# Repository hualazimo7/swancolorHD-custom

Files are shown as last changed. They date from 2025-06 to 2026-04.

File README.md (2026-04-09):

# swancolorHD
An open-source WonderSwan Color consolizer.

This project is in a somewhat usable stage right now.
Additionally, it needs the video core from sameer, to be [found here](https://github.com/hdl-util/hdmi).

## About
This project is an open-source consolizer for the WonderSwan Color handheld, based on a Tang Nano 9k FPGA board (which has a GW1NR-LV9QN88P FPGA on it).

Custom version [here](./PCB_CSUTOM/)  
Lite version [here](./Lite/)  

## PCB


### PCB BOM
| **Reference** | **Part** | **Link** |
---------|------|------|
|FPC1    | FFC connector with 24 pins, 0.5mm pitch, bottom contacts | [LCSC](https://lcsc.com/product-detail/FFC-FPC-Connectors_XUNPU-FPC-05F-24PH20_C2856805.html)|
|U1      | Arduino Nano | [AliExpress](https://aliexpress.com/item/1005002966043359.html)|
|U2      | Tang Nano 9k | [AliExpress](https://aliexpress.com/item/1005004275570427.html)|
|U3      | TPS62221DDCR | [LCSC](https://lcsc.com/product-detail/DC-DC-Converters_Texas-Instruments-TPS62221DDCR_C398348.html)|
|USB1    | Micro USB connector | [LCSC](https://lcsc.com/product-detail/USB-Connectors_XKB-Connectivity-U254-051T-4BH23-S2S_C482361.html)|
|JOY1    | SNES controller connector 90° | [AliExpress](https://aliexpress.com/item/32895254743.html)|
|C1      | 4.7 uF capacitor (1206) | [LCSC](https://lcsc.com/product-detail/Multilayer-Ceramic-Capacitors-MLCC-SMD-SMT_FH-Guangdong-Fenghua-Advanced-Tech-1206B475K500NT_C29823.html)|
|C2 | 10 uF capacitor (1206) | [LCSC](https://lcsc.com/product-detail/Multilayer-Ceramic-Capacitors-MLCC-SMD-SMT_Samsung-Electro-Mechanics-CL31A106KBHNNNE_C13585.html)|
|L2 | 10 uH inductivity (1206) | [LCSC](https://lcsc.com/product-detail/Inductors-SMD_FH-Guangdong-Fenghua-Advanced-Tech-CMI321609X100KT_C1051.html)|
|Q1 - Q12 | N-channel MOSFET 2N7002 (SOT-23) |[LCSC](https://lcsc.com/product-detail/MOSFETs_Jiangsu-Changjing-Electronics-Technology-Co-Ltd-2N7002_C8545.html)|

## PCB Wiring Diagram
Check the [wiring diagram from WSC motherboard to PCB in the assets folder](./assets/wiring.png) for full zoom.


**Connections on the WSC backside:**
| WSC Motherboard | Consolizer PCB |
|---|---|
| Battery + | 1V5 |
| Battery - | GND |

## Display Connector
Use a 24 pin same-side (also known as "type A") flex cable with 0.5 mm pitch to connect the display FFC connector of the WSC motherboard to the PCB FFC connector.

## Manual Wiring (without PCB)
The display signals can be easily wired to the FPGA board by using an FFC breakout board and an FFC cable.
The required FFC is 24 pins with 0.5 mm pitch.

| WSC display pin | Tang Nano 9k pin |
|---|---|
| 19 | GND |
| 22 | 86 |
| 21 | 85 |
| 23 | 84 |
| 18 | 83 |
| 14 | 82 |
| 15 | 81 |
| 16 | 80 |
| 17 | 79 |
| 10 | 25 |
| 11 | 26 |
| 12 | 27 |
| 13 | 28 |
| 6 | 29 |
| 7 | 30 |
| 8 | 33 |
| 9 | 34 |

## Controller
The swancolorHD uses a SNES controller.
Any regular SNES controller should work.

You can also turn an empty WonderSwan Color into a controller using the [**swantroller** project](https://github.com/zwenergy/swantroller).
This turns the WSC shell into a controller with a SNES plug.
Note, that the current version is only to be used with the WSC consolizer, not a regular SNES console.
The reason for this is that the swantroller uses a different button layout as a SNES controller.
swantroller

## SNES Controller Mapping
The controller mapping differs for landscape and portrait mode.
### Landscape Mode
By default, the SNES DPAD is mapped to the X buttons of the WonderSwan. 
The controller's B & Y buttons are mapped to the WonderSwan's B button, A & Y are mapped to A. 
Start is mapped to Start.

To control the WS Y buttons, use the L or R shoulder buttons.
When holding L, the SNES DPAD is mapped to the WS Y buttons.
When holding R, A/B/X/Y are mapped to Y2/Y3/Y1/Y4.

For the few games, which require to hold X & Y & A/B buttons at the same time, an alternative input mode is existing.
In this alternative input mode, the Y buttons are mapped to the DPAD, the X buttons are mapped to A/B/X/Y.
The WS B button is mapped to the SNES L button and the WS A button is mapped to the SNES R button.
To enter or exit this alternative input mode, press **L + R + START + DPAD DOWN**.

|SNES Button | WS Button (no shoulder button held) | WS Button (holding L) | WS Button (holding R )| WS Button (alternative input mode) |
|---|---|---|---|---|
|UP | X1 | Y1 | X1 | Y1 |
|DOWN | X3 | Y3 | X3 | Y3 |
|LEFT | X4 | Y4 | X4 | Y4 |
|RIGHT | X2 | Y2 | X2 | Y2 |
|A | A | A | Y2 | X2 |
|B | B | B | Y3 | X3 |
|X | A | A | Y1 | X1 |
|Y | B | B | Y4 | X4 |
|L | - | - | - | B |
|R | - | - | - | A |
|START | START | START | START | START |

### Portrait Mode
The SNES DPAD is mapped to the Y buttons of the WonderSwan (rotated accordingly).
Y is mapped to X1, X is mappped to X2, A is mapped to X3 and B is mapped to X4.
Start is mapped to Start.

## Switching from Landscape Mode to Portrait Mode
In order to switch from landscape to portrait mode (or vice versa), just press the "Select" button on the SNES gamepad.

## Switching from Landscape Mode to Portrait Mode without Video Rotation
If you want to use the video out with a properly rotated display for portrait mode games (so actually rotate the display itself), you want to have the portrait mode gamepad mapping but without the video being rotated from the consolizer.
For this, you can activate (and deactivate) portrait mode controller mapping without video rotation via the button combination: **L + R + START + DPAD UP**.

## Disclaimer
**Use the files and/or schematics to build your own board at your own risk**.
This board works fine for me, but it's a simple hobby project, so there is no liability for errors in the schematics and/or board files.
**Use at your own risk**.

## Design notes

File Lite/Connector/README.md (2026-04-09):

# swancolorHD Lite FPC

## About
This is an Connector PCB for the swancolorHD Lite.  
Place it in the battery compartment of the Wonderswan Color.    
When ordering, please select the items indicated by the red box in order_fpc.png.

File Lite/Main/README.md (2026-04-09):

# swancolorHD Lite main pcb

## About
This board is a customized version of the swancolorHD main board developed by [zwenergy](https://github.com/zwenergy).  

The changes are as follows:  
- Adding a main power switch  
- Change to USB Type-C power supply   
- Remove controller parts  
- Changed connection with WonderSwan color pcb to [FPC](../FPC/) + [Connector PCB](../Connector/)  

### PCB BOM
| **Reference** | **Part** | **Link** |
|---|---|---|
|FPC1| FFC connector with 24 pins, 1.0mm pitch, bottom contacts | [LCSC](https://www.lcsc.com/product-detail/C3446114.html)|
|U1  | Tang Nano 9k | [AliExpress](https://aliexpress.com/item/1005004275570427.html)|
|U2  | TPS62221DDCT | [LCSC](https://www.lcsc.com/product-detail/C2073237.html)|
|C1  | 4.7 uF capacitor (1206) | - |
|C2  | 22 uF capacitor (1206) | - |
|L1  | 4.7uH Inductors (1206) | - |
|CN1 | B2B-PH-K-S | - |
|CN2 | B4B-PH-K-S(LF)(SN) | - |
|SW1, SW2 | SK12D07VG6 | - |
|R3  | 220 Ω resistor (1206) | - |
|R4  | 220 kΩ resistor (1206) | - |

* Implement either R3 or R4.  
* Implement either U2,C1,C2,L1 or [ASM1117 1.5V DC-DC Converter Module](https://ja.aliexpress.com/item/1005006043683365.html) (Please pay attention to the orientation of the power supply).  

### Other Parts  
| **Part** | **Link** |
|---|---|
| 24pin 1.0mm pitch Forward Direction(Type-B) FFC 1000mm | [AliExpress](https://aliexpress.com/item/1005006889063970.html)|
| USB Type-C power supply connector female | [AliExpress](https://aliexpress.com/item/1005006297697300.html)|
| self-locking switch 3-6V 8mm dia with LED | [AliExpress](https://aliexpress.com/item/1005005628118782.html)|
| header socket 1x24  (2 pcs)| - |

* Please change the FFC to your preferred length.

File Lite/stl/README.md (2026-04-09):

# swancolorHD Lite case

## About
This is the STL data of the case designed for the [swancolorHD Lite main pcb](../Main/).  

### Other Parts  
| **Part** | **Link** |
|---|---|
| insert nut M2(OD3.5mm) Length 3.5mm (4 pcs)| [AliExpress](https://aliexpress.com/item/1005003582355741.html) |
| M2 x 5mm pan head screw (4 pcs)| [AliExpress](https://aliexpress.com/item/1005002364189187.html) |
| insert nut M3(OD4.2mm) Length 4mm (4 pcs)| [AliExpress](https://aliexpress.com/item/1005003582355741.html) |
| Gb839 screw Length 6mm (4 pcs)| [AliExpress](https://aliexpress.com/item/1005006173570612.html) |

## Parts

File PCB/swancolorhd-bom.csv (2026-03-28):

Comment | Designator | Footprint | JLCPCB Part #�ioptional�j
FFC connector with 24 pins, 0.5mm pitch, bottom contacts | FPC1 |  | C2856805
TPS62221DDCT | U3 |  | C2073237
Micro USB connector | USB1 |  | C482361
4.7 uF | C1 |  | C29823
10 uF | C2 |  | C13585
10 uH | L2 |  | C1051
N-channel MOSFET 2N7002 (SOT-23) | Q1,Q2,Q3,Q4,Q5,Q6,Q7,Q8,Q9,Q10,Q11,Q12 |  | C8545

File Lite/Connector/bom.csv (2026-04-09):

Designator | Footprint | Quantity | Value | LCSC Part #
CN1 | CONN-SMD_2P-P1.00_SM02B-SRSS-TB-LF-SN | 1 | ~
FPC1 | FPC-SMD_24P-P0.50_FPC-05F-24PH20 | 1 | ~
FPC2 | FPC-SMD_24P-P1.00_XUNPU_FPC-1.0AX-24PWBH25 | 1 | ~

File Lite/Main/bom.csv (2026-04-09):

Designator | Footprint | Quantity | Value | LCSC Part #
C1 | 1206 | 1 | 4.7uF
C2 | 1206 | 1 | 22uF
CN1 | CONN-TH_B2B-PH-K-S | 1 | USB_PW(5V)
CN2 | CONN-TH_B4B-PH-K-S | 1 | SWITCH
FPC1 | FPC-SMD_24P-P1.00_XUNPU_FPC-1.0AX-24PWBH25 | 1 | ~
L1 | 1206 | 1 | 4.7uH
R3 | 1206 | 1 | 220
U2 | SOT-23-5_L2.9-W1.6-P0.95-LS2.8-BL | 1 | TPS62221DDCT

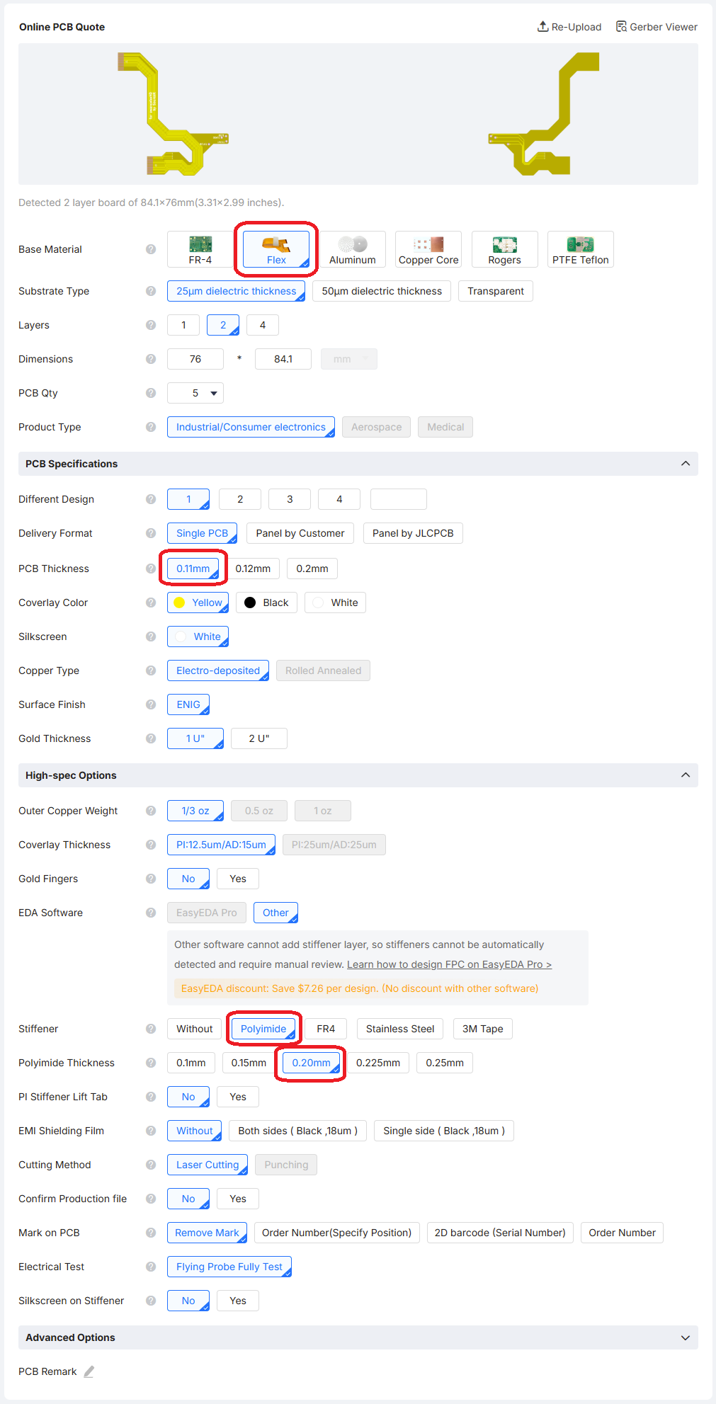
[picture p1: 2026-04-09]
Lite/FPC/order_fpc.png

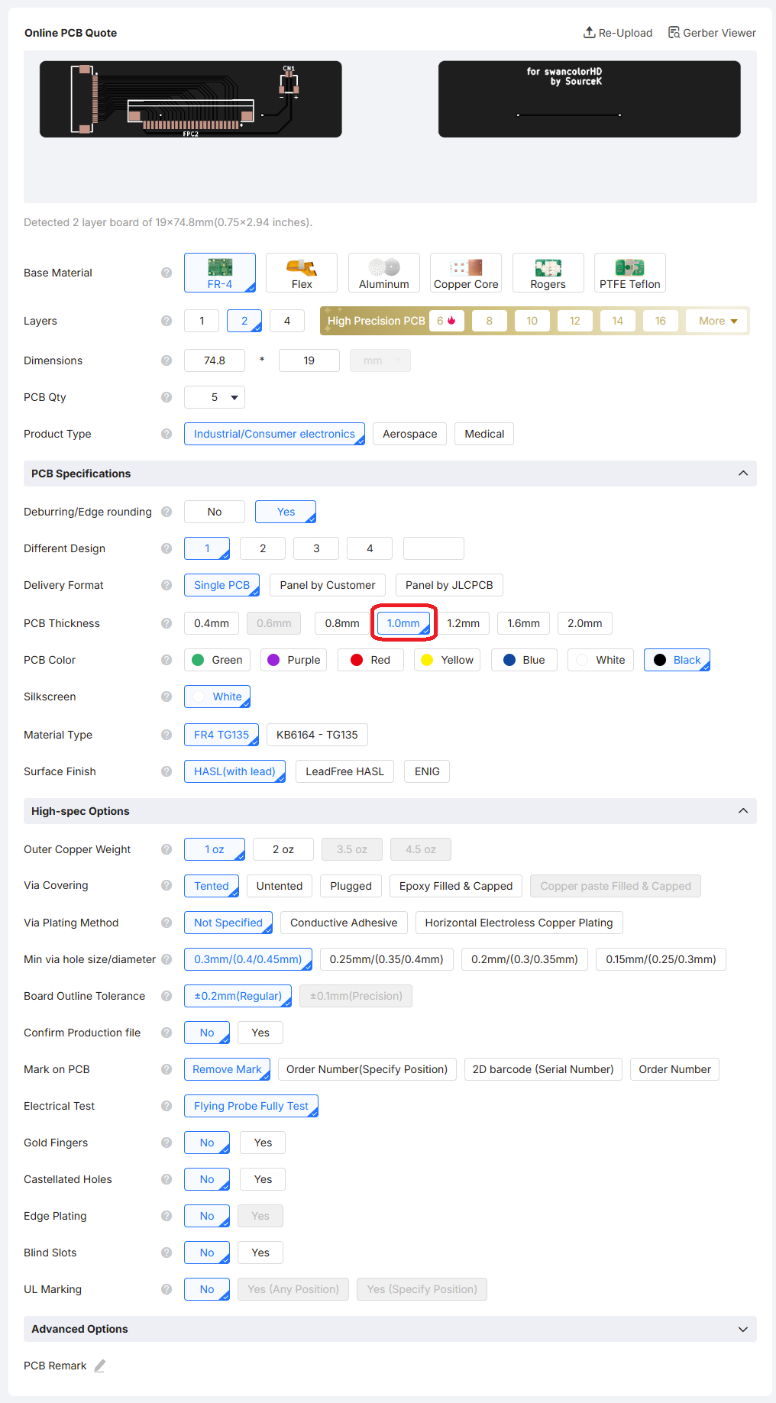
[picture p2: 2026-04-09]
Lite/Connector/order_pcb.png

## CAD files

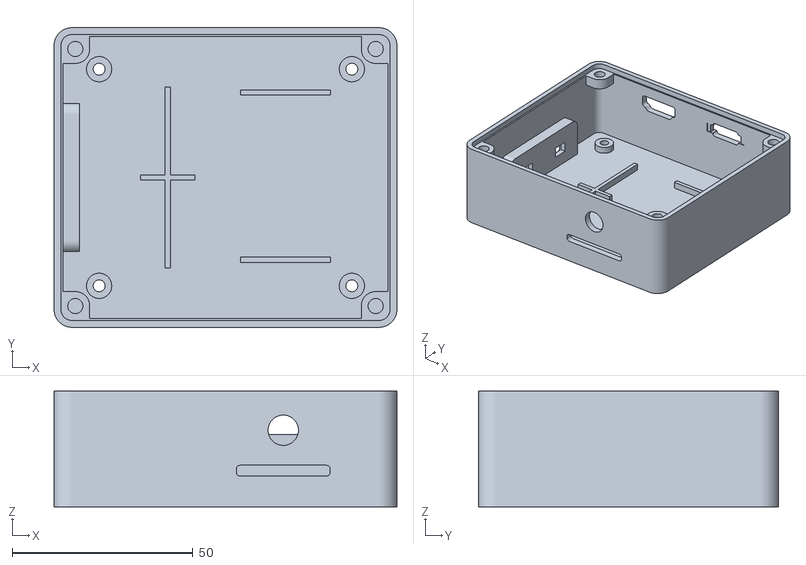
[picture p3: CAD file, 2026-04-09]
Lite/stl/swancolor_Lite_Case.stl
95.0 x 83.0 x 32.0

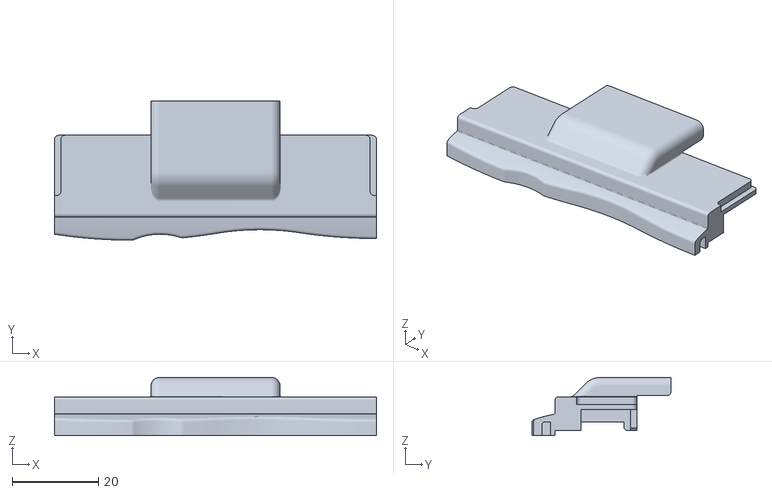
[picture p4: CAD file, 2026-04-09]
Lite/stl/swancolorHD_Lite_Connector_Cover.stl
74.8 x 32.4 x 13.5

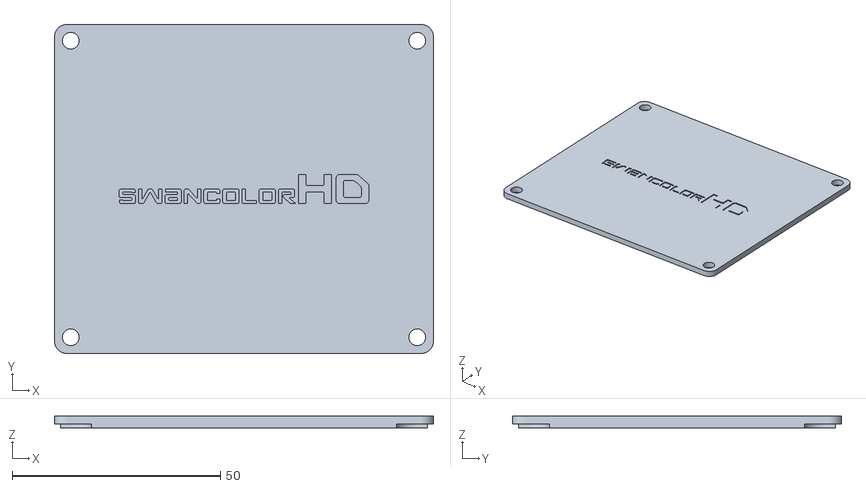
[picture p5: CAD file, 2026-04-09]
Lite/stl/swancolor_Lite_Lid_3DPrint.stl
91.0 x 79.0 x 3.00

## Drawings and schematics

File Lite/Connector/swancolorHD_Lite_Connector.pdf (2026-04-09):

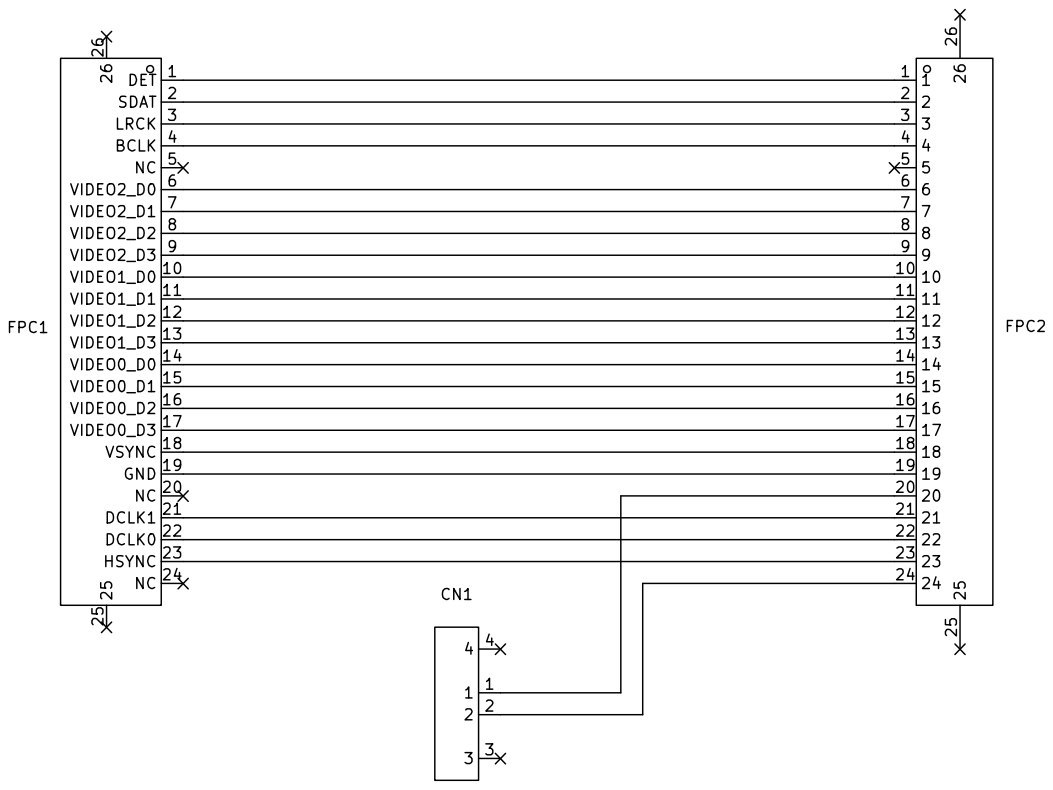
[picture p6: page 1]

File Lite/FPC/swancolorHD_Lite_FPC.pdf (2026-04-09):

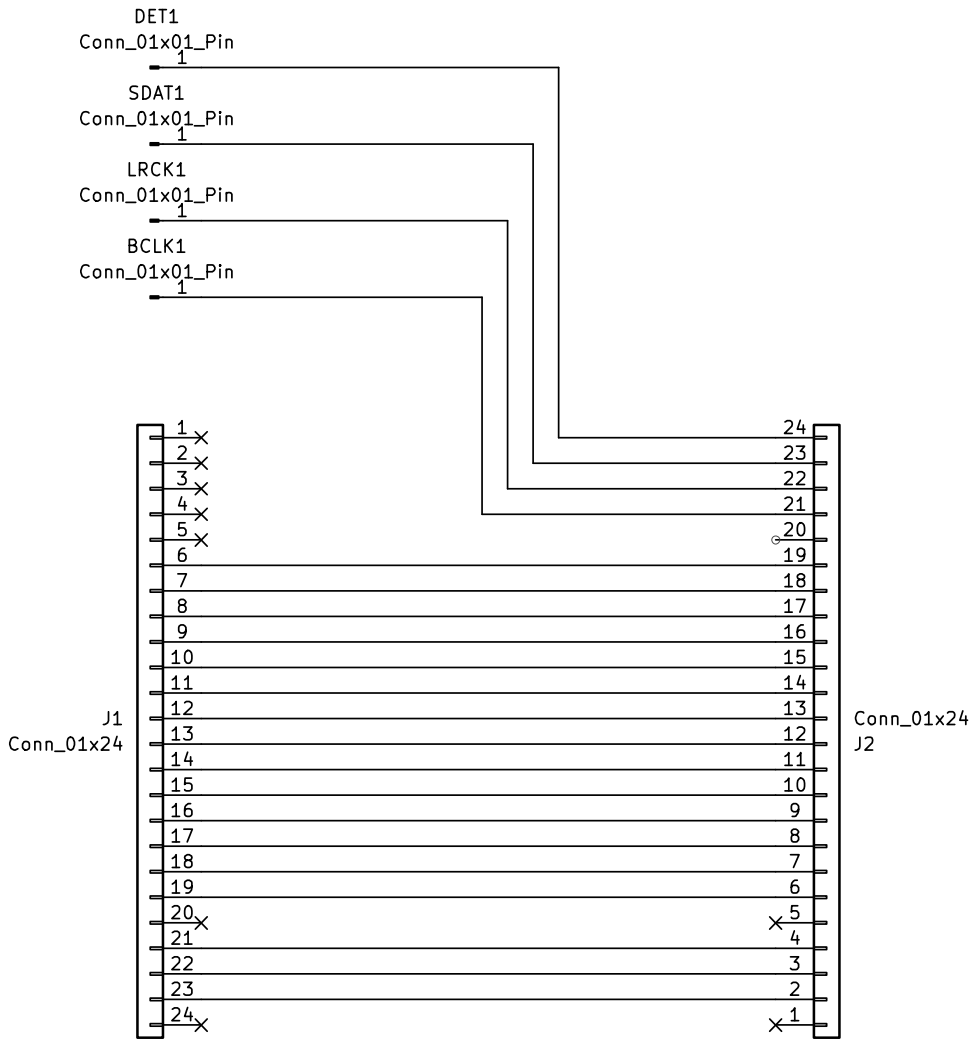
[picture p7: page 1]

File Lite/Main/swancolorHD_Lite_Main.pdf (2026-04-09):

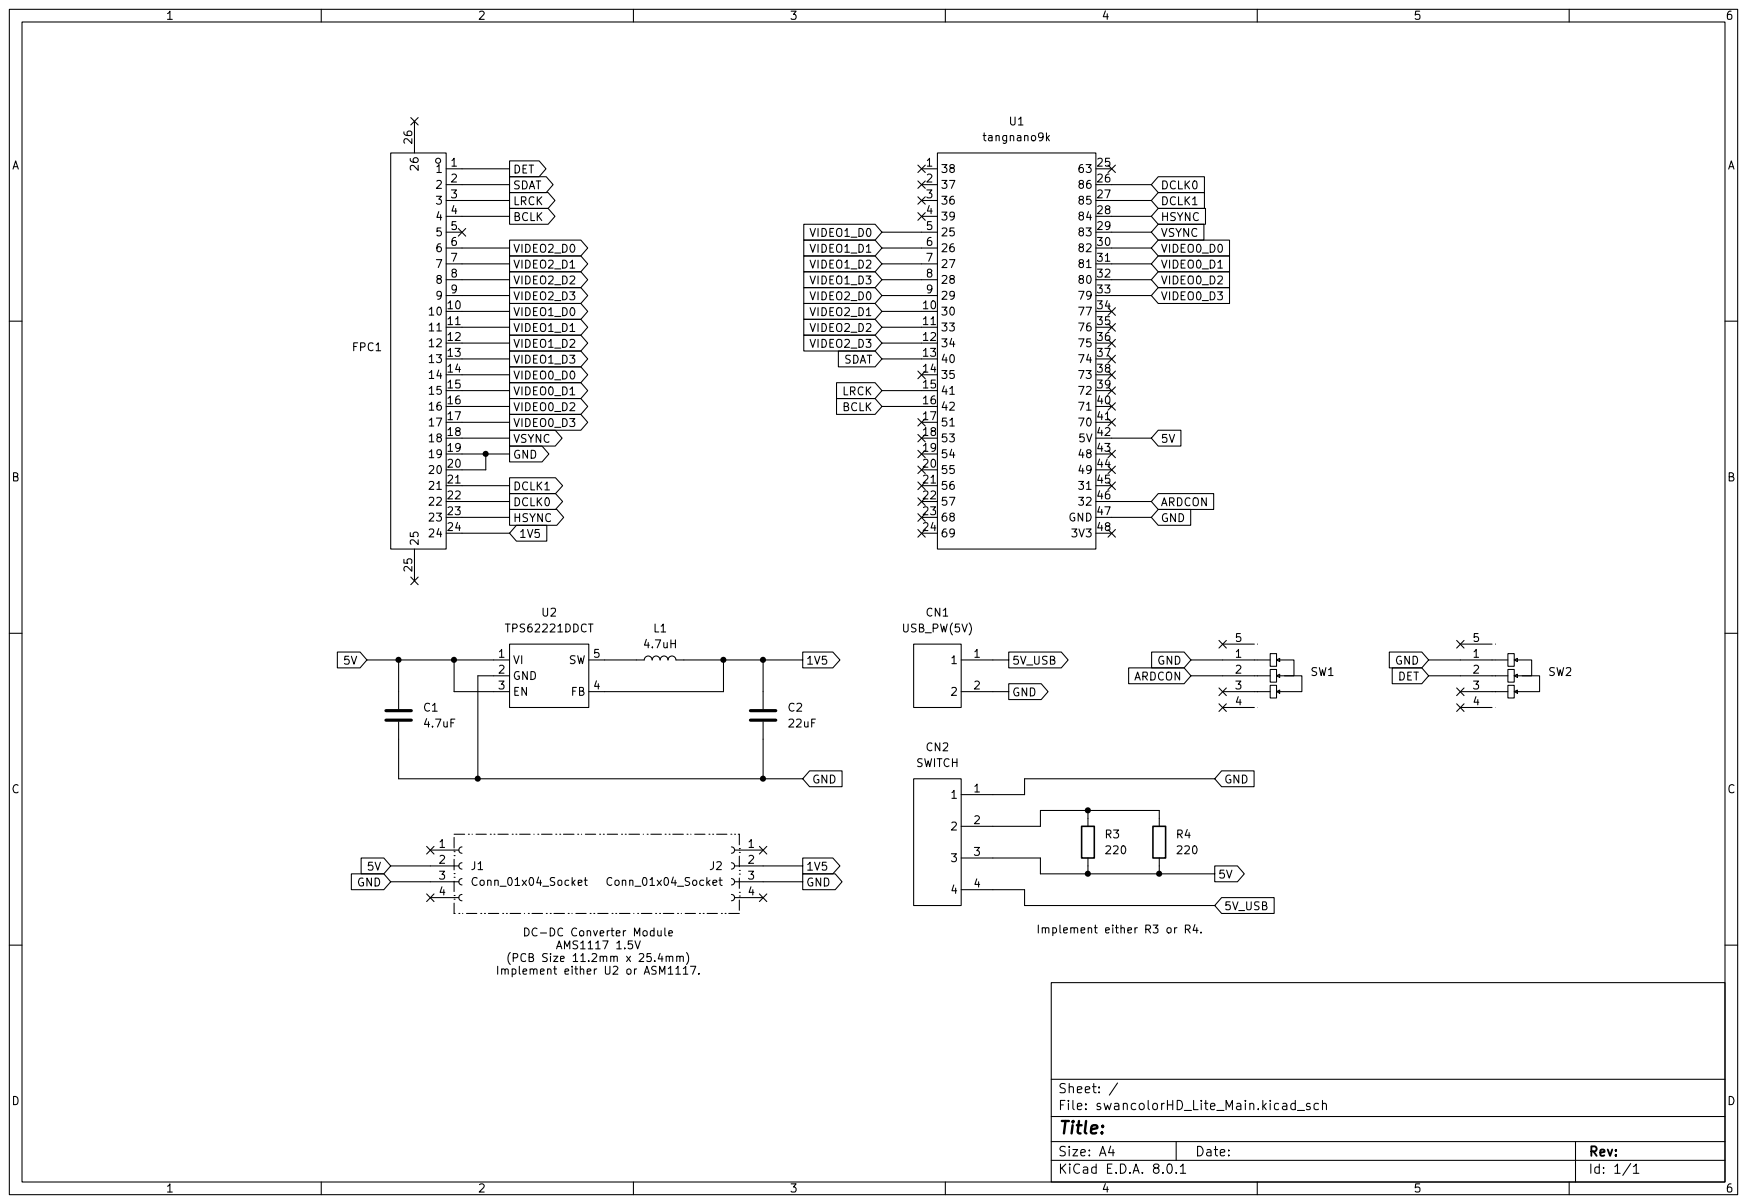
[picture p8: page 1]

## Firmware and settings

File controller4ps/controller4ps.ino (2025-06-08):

/******************************************************************
 * title    : controller for swancolorHD
 * Autor    : zwenergy
 * modified : SourceK
 ******************************************************************/
#include <DigitalIO.h>
#include <PsxControllerBitBang.h>

#include <avr/pgmspace.h>
typedef const __FlashStringHelper * FlashStr;
typedef const byte* PGM_BYTES_P;
#define PSTR_TO_F(s) reinterpret_cast<const __FlashStringHelper *> (s)

const byte PIN_PS2_ATT = 16;
const byte PIN_PS2_CMD = 14;
const byte PIN_PS2_DAT = 15;
const byte PIN_PS2_CLK = 13;

const byte PIN_BUTTONPRESS = A4;
const byte PIN_HAVECONTROLLER = A5;

const char buttonSelectName[] PROGMEM = "Select";
const char buttonL3Name[] PROGMEM = "L3";
const char buttonR3Name[] PROGMEM = "R3";
const char buttonStartName[] PROGMEM = "Start";
const char buttonUpName[] PROGMEM = "Up";
const char buttonRightName[] PROGMEM = "Right";
const char buttonDownName[] PROGMEM = "Down";
const char buttonLeftName[] PROGMEM = "Left";
const char buttonL2Name[] PROGMEM = "L2";
const char buttonR2Name[] PROGMEM = "R2";
const char buttonL1Name[] PROGMEM = "L1";
const char buttonR1Name[] PROGMEM = "R1";
const char buttonTriangleName[] PROGMEM = "Triangle";
const char buttonCircleName[] PROGMEM = "Circle";
const char buttonCrossName[] PROGMEM = "Cross";
const char buttonSquareName[] PROGMEM = "Square";

const char* const psxButtonNames[PSX_BUTTONS_NO] PROGMEM = {
  buttonSelectName,
  buttonL3Name,
  buttonR3Name,
  buttonStartName,
  buttonUpName,
  buttonRightName,
  buttonDownName,
  buttonLeftName,
  buttonL2Name,
  buttonR2Name,
  buttonL1Name,
  buttonR1Name,
  buttonTriangleName,
  buttonCircleName,
  buttonCrossName,
  buttonSquareName
};

PsxControllerBitBang<PIN_PS2_ATT, PIN_PS2_CMD, PIN_PS2_DAT, PIN_PS2_CLK> psx;

boolean haveController = false;

// ps mode ?
boolean psMode = false;

// bemani mode?
uint8_t bemaniMode = 0;
uint8_t intBemaniComboPrev = 0;
uint8_t intBemaniCombo = 0;
uint8_t intBemaniUpDownPrev = 0;

// Add PS L2,R2 buttons temporarily. 
uint8_t snesL2 = 0;
uint8_t snesR2 = 0;

const unsigned long PSMODE_POLLING_INTERVAL = 1000U / 120U;

boolean enableSwantrollerBLE = false;
uint8_t buf[19];
uint16_t ble_data = 0;

byte psxButtonToIndex (PsxButtons psxButtons) {
  byte i;

  for (i = 0; i < PSX_BUTTONS_NO; ++i) {
    if (psxButtons & 0x01) {
      break;
    }

    psxButtons >>= 1U;
  }

  return i;
}

uint16_t bytesToUint16LE(const uint8_t *bytes) {
    return (uint16_t)bytes[0] |
           ((uint16_t)bytes[1] << 8);
}

void dumpButtons (PsxButtons psxButtons, uint8_t *snesUP, uint8_t *snesDOWN, uint8_t *intBemaniUpDownPrev, uint8_t bemaniMode) {
  static PsxButtons lastB = 0;

  if (psxButtons != lastB) {
    lastB = psxButtons;     // Save it before we alter it
    String buttonName = "";
    
    Serial.print (F("Pressed: "));

    for (byte i = 0; i < PSX_BUTTONS_NO; ++i) {
      byte b = psxButtonToIndex (psxButtons);
      if (b < PSX_BUTTONS_NO) {
        PGM_BYTES_P bName = reinterpret_cast<PGM_BYTES_P> (pgm_read_ptr (&(psxButtonNames[b])));
        buttonName = PSTR_TO_F (bName);
        Serial.print (buttonName);
      }

      // When "bemani mode" is enabled, the input is forcibly released when there is a new UP/DOWN input.
      if ((buttonName == "Up" || buttonName == "Down") && bemaniMode){ 
        if (*intBemaniUpDownPrev) {
          *snesUP = 0;
          *snesDOWN = 0;
          *intBemaniUpDownPrev = 0;
        } else {
          *intBemaniUpDownPrev = 1;
        }
      }

      psxButtons &= ~(1 << b);

      if (psxButtons != 0) {
        Serial.print (F(", "));
      }
    }

    Serial.println ();
  }
}

// Pin definitions.
// WS outputs.
// These definitions are just for reference. If other pins should be used,
// the updateWonderSignals function needs to be adjusted.
#define X1 2
#define X2 3
#define X3 4
#define X4 5
#define Y1 6
#define Y2 7
#define Y3 8
#define Y4 9
#define BUTA 10 
#define BUTB 11
#define BUTSTART 12

// SNES controller.
#define SNESLATCH A0
#define SNESCLK A1
#define SNESSERIAL A2

#define ARDCON A3

// Polling interval in ms.
#define POLLINT 2

// Some NOP definitions.
// Yes, this is very pretty. But we do not have code size problems,
// hence using stupid sequences of NOPs makes it nicely timing 
// predictable.
#define NOP1 asm volatile( "nop\n" )
#define NOP5 NOP1; NOP1; NOP1; NOP1; NOP1
#define NOP10 NOP5; NOP5
#define NOP20 NOP10; NOP10
#define NOP40 NOP20; NOP20
#define NOP80 NOP40; NOP40

#define WAIT2US NOP20; NOP10; NOP1
#define WAIT8US NOP80; NOP40; NOP5; NOP1; NOP1; NOP1

// The latest controller state.
uint8_t conA;
uint8_t conB;
uint8_t conX1;
uint8_t conX2;
uint8_t conX3;
uint8_t conX4;
uint8_t conY1;
uint8_t conY2;
uint8_t conY3;
uint8_t conY4;
uint8_t conStart;

// Rotate mode?
uint8_t rotate = 0;
uint8_t selectPrev = 0;
uint8_t powerPrev = 0;

// Internal rotate mode?
// (only rotate the controls, not the video)
uint8_t rotateInt = 0;
uint8_t intRotateComboPrev = 0;

// Video only rotation?
// (only used with the swantroller).
uint8_t rotateVideoOnly = 0;

// Alternative input mode?
// X buttons => ABXY
// Y buttons => DPAD
// A/B => L/R
uint8_t altInput = 0;
uint8_t altInputComboPrev = 0;

// Read the controller.
void readController() {

  // Hold SNES buttons temporarily.
  uint8_t snesUP = 0;
  uint8_t snesDOWN = 0;
  uint8_t snesLEFT = 0;
  uint8_t snesRIGHT = 0;
  uint8_t snesSTART = 0;
  uint8_t snesSELECT = 0;
  uint8_t snesX = 0;
  uint8_t snesY = 0;
  uint8_t snesA = 0;
  uint8_t snesB = 0;
  uint8_t snesL = 0;
  uint8_t snesR = 0;

  // For swantroller.
  uint8_t snesDat12 = 0;
  uint8_t snesDat13 = 0;
  uint8_t snesDat14 = 0;

  conX1 = 0;
  conX2 = 0;
  conX3 = 0;
  conX4 = 0;
  conY1 = 0;
  conY2 = 0;
  conY3 = 0;
  conY4 = 0;
  conA = 0;
  conB = 0;
  conStart = 0;

  if ( psMode ) {
    static byte slx, sly, srx, sry;

    fastDigitalWrite (PIN_HAVECONTROLLER, haveController);
    
    if (!haveController) {
      if (psx.begin ()) {
        Serial.println (F("Controller found!"));
        delay (300);
        if (!psx.enterConfigMode ()) {
          Serial.println (F("Cannot enter config mode"));
        } else {
          if (!psx.enableAnalogSticks (false)) {
            Serial.println (F("Cannot disable analog sticks"));
          }
          if (!psx.enableAnalogButtons (false)) {
            Serial.println (F("Cannot disable analog buttons"));
          }
          if (!psx.enableRumble (false)) {
            Serial.println (F("Cannot disable rumble"));
          }
          if (!psx.exitConfigMode ()) {
            Serial.println (F("Cannot exit config mode"));
          }
        }

        haveController = true;
      }
    } else {
      if (!psx.read ()) {
        Serial.println (F("Controller lost :("));
        haveController = false;
      } else {
        fastDigitalWrite (PIN_BUTTONPRESS, !!psx.getButtonWord ());
        
        // assign ps controller signal
        snesSELECT = psx.buttonPressed(PSB_SELECT);
        snesSTART = psx.buttonPressed(PSB_START);
        snesUP = psx.buttonPressed(PSB_PAD_UP);
        snesRIGHT = psx.buttonPressed(PSB_PAD_RIGHT);
        snesDOWN = psx.buttonPressed(PSB_PAD_DOWN);
        snesLEFT = psx.buttonPressed(PSB_PAD_LEFT);
        snesL2 = psx.buttonPressed(PSB_L2);
        snesR2 = psx.buttonPressed(PSB_R2);
        snesL = psx.buttonPressed(PSB_L1);
        snesR = psx.buttonPressed(PSB_R1);
        snesX = psx.buttonPressed(PSB_TRIANGLE);
        snesA = psx.buttonPressed(PSB_CIRCLE);
        snesB = psx.buttonPressed(PSB_CROSS);
        snesY = psx.buttonPressed(PSB_SQUARE);
        
        dumpButtons (psx.getButtonWord (), &snesUP, &snesDOWN, &intBemaniUpDownPrev, bemaniMode);
      }
    }

    delay (PSMODE_POLLING_INTERVAL);

  } else {

    // Set the latch to high for 12 us.
    digitalWrite( SNESLATCH, 1 );
    delayMicroseconds( 12 );
    digitalWrite( SNESLATCH, 0 );
    delayMicroseconds( 6 );

    // BLE
    if ( Serial.available() ) {
      Serial.readBytes(buf, 19);
      ble_data = bytesToUint16LE(buf);
      Serial.println(ble_data);
    }

    // Shift in the controller data.
    // Logic 0 means pressed.
    for ( uint8_t i = 0; i < 16; ++i ) {
      digitalWrite( SNESCLK, 0 );
      delayMicroseconds( 6 );
      // We only care about the first 15 bits.
      if ( i < 15 ) {
        uint8_t curDat = !digitalRead( SNESSERIAL );
        // BLE
        if ( ble_data != 0 ) {
          curDat = (ble_data >> i) & 1;
        }
        switch ( i ) {
          case 0:
            snesB = curDat;
            break;
          case 1:
            snesY = curDat;
            break;
          case 2:
            snesSELECT = curDat;
            break;
          case 3:
            snesSTART = curDat;
            break;
          case 4:
            // Up
            snesUP = curDat;
            break;
          case 5:
            // Down
            snesDOWN = curDat;
            break;
          case 6:
            // Left
            snesLEFT = curDat;
            break;
          case 7:
            // Right
            snesRIGHT = curDat;
            break;
          case 8:
            snesA = curDat;
            break;
          case 9:
            snesX = curDat;
            break;
          case 10:
            snesL = curDat;
            break;
          case 11:
            snesR = curDat;
            break;
          case 12:
            snesDat12 = curDat;
            break;
          case 13:
            snesDat13 = curDat;
            break;
          case 14:
            snesDat14 = curDat;
            break;
          default:
            break;
          
        }
      }
      digitalWrite( SNESCLK, 1 );
      delayMicroseconds( 6 );
    }
  }

  uint8_t intRotateCombo = snesL && snesR && snesSTART && snesUP;
  uint8_t altInputCombo = snesL && snesR && snesSTART && snesDOWN;

  // At very first, decide whether we have a regular controller
  // or a swantroller. This is done by checking if UP and DOWN are "pressed".
  if ( snesUP && snesDOWN ) {
    // We have swantroller (... or a broken SNES controller).
    conX1 = snesB;
    conX2 = snesY;
    conX3 = snesSELECT;
    conX4 = snesSTART;
    conY1 = snesLEFT;
    conY2 = snesRIGHT;
    conY3 = snesA;
    conY4 = snesX;
    conA = snesL;
    conB = snesR;
    conStart = snesDat12;

    // The POWER button is transmitted as the 14th bit, the SOUND via 13th bit.
    // We currently use the POWER button for video rotation only.
    if ( !powerPrev && snesDat14 ) {
      rotateVideoOnly = !rotateVideoOnly;
    }

  } else {
    // Regular SNES controller.
    // Do the mapping.
    conStart = snesSTART;
  
    // Pressing SELECT toggles rotate.
    if ( !selectPrev && snesSELECT ) {
      rotate = !rotate;
    }
  
    // Internal rotate?
    if ( !intRotateComboPrev && intRotateCombo ) {
      rotateInt = !rotateInt;
    } else if ( !altInputComboPrev && altInputCombo ) {
      altInput = !altInput;
    }

    // bemani mode? (ps mode only)
    intBemaniCombo = psMode && snesL && snesR && snesB && snesY && snesSTART;
    if ( !intBemaniComboPrev && intBemaniCombo ) {
      bemaniMode = !bemaniMode;
      Serial.print("Bemani Mode = ");
      Serial.println(bemaniMode);
    }

    if ( psMode ) {
      // Rotated screen?
      if (( rotate || rotateInt ) && !bemaniMode) {
        conY2 = snesUP;
        conY3 = snesRIGHT;
        conY4 = snesDOWN;
        conY1 = snesLEFT;
    
        conX2 = snesX;
        conX3 = snesA;
        conX4 = snesB;
        conX1 = snesY;
        conA = snesR;
        conB = snesL;
  
      // Bemani mode?
      } else if ( bemaniMode ) {
        conY1 = snesY;
        conY2 = snesL;
        conY3 = snesB;
        conY4 = 0;
  
        conX1 = 0;
        conX2 = snesR;
        conX3 = snesA;
        conX4 = 0;
        conA = 0;
        conB = snesUP | snesDOWN | snesL2 | snesLEFT;

        // Press the START button when you want to select music on the turntable.
        if ( snesSTART ) {
          conY1 = snesUP;
          conY3 = snesDOWN;
          conY2 = snesL;
          conY4 = snesY;
          conX3 = snesLEFT | snesA | snesB;
          conX4 = snesR | snesL2;
          conB = 0;
        }
      } else {
        // Not rotated screen.
        conX1 = snesUP;
        conX2 = snesRIGHT;
        conX3 = snesDOWN;
        conX4 = snesLEFT;
    
        conB = snesB |snesY;
        conA = snesA |snesX;
        conY1 = snesL;
        conY2 = snesR;
        conY3 = snesR2;
        conY4 = snesL2;
      }
    } else {
      // Rotated screen?
      if ( rotate || rotateInt ) {
        conY2 = snesUP;
        conY3 = snesRIGHT;
        conY4 = snesDOWN;
        conY1 = snesLEFT;
    
        conX2 = snesX;
        conX3 = snesA;
        conX4 = snesB;
        conX1 = snesY;
        
      } else {
        // Not rotated screen.
        
        //  Regular input mode.
        if ( !altInput ) {
          // In case L is pressed, we map the WS Y buttons to the DPAD.
          if ( snesL ) {
            conY1 = snesUP;
            conY2 = snesRIGHT;
            conY3 = snesDOWN;
            conY4 = snesLEFT;
          } else {
            conX1 = snesUP;
            conX2 = snesRIGHT;
            conX3 = snesDOWN;
            conX4 = snesLEFT;
          }
        
          // In case R is pressed, we map the WS Y buttons to the A/B/X/Y.
          if ( snesR ) {
            conY1 = snesX;
            conY2 = snesA;
            conY3 = snesB;
            conY4 = snesY;
          } else {
            conB = snesB |snesY;
            conA = snesA |snesX;
          }

        } else {
          // Alternative input mode. Useful for, e.g., Rhyme Rider Kerorican.
          conY1 = snesUP;
          conY2 = snesRIGHT;
          conY3 = snesDOWN;
          conY4 = snesLEFT;

          conX1 = snesX;
          conX2 = snesA;
          conX3 = snesB;
          conX4 = snesY;

          conB = snesL;
          conA = snesR;

        }
      }
    }
  }

  selectPrev = snesSELECT;
  intRotateComboPrev = intRotateCombo;
  powerPrev = snesDat14;
  altInputComboPrev = altInputCombo;
  intBemaniComboPrev = intBemaniCombo;
}

// Drive WS controller signals.
void updateWonderSignals() {
  // Get D0 and D1 values.
  uint8_t d1d0 = PORTD;
  d1d0 = d1d0 & 0b00000011;
  uint8_t dat = d1d0 | ( conX1 << 2 ) | ( conX2 << 3 ) | ( conX3 << 4 ) |
    ( conX4 << 5 ) | ( conY1 << 6 ) | ( conY2 << 7 );
  // Write them.
  PORTD = dat;

  uint8_t d13 = PORTB;
  d13 = d13 & 0b11100000;
  // The next ones.
  dat = d13 | ( conY3 ) | ( conY4 << 1 ) | ( conA << 2 ) | ( conB << 3 ) | 
    ( conStart << 4 );
  PORTB = dat; 

}

void doComm() {
  if ( rotate || rotateVideoOnly ) {
    // Actuall drive GND.
    pinMode( ARDCON, OUTPUT );
  } else {
    // High Z.
    pinMode( ARDCON, INPUT );
  }
}

void setup() {
  fastPinMode (PIN_BUTTONPRESS, OUTPUT);
  fastPinMode (PIN_HAVECONTROLLER, OUTPUT);
  
  delay (300);
  
  // DEBUG.
  Serial.begin(115200);
  Serial.println( "Startup" );
  
  // Set up pin modes.
  // First set all output registers of WS buttons to 0.
  pinMode( X1, OUTPUT );
  digitalWrite( X1, 0 );
  pinMode( X2, OUTPUT );
  digitalWrite( X2, 0 );
  pinMode( X3, OUTPUT );
  digitalWrite( X3, 0 );
  pinMode( X4, OUTPUT );
  digitalWrite( X4, 0 );

  pinMode( Y1, OUTPUT );
  digitalWrite( Y1, 0 );
  pinMode( Y2, OUTPUT );
  digitalWrite( Y2, 0 );
  pinMode( Y3, OUTPUT );
  digitalWrite( Y3, 0 );
  pinMode( Y4, OUTPUT );
  digitalWrite( Y4, 0 );
  
  pinMode( BUTA, OUTPUT );
  digitalWrite( BUTA, 0 );
  pinMode( BUTB, OUTPUT );
  digitalWrite( BUTB, 0 );
  
  pinMode( BUTSTART, OUTPUT );
  digitalWrite( BUTSTART, 0 );

  pinMode( ARDCON, OUTPUT );
  digitalWrite( ARDCON, 0 );
  pinMode( ARDCON, INPUT );

  modeCheck();
}

void modeCheck() {
  // swantroller check
  // Hold swantroller buttons temporarily.
  uint8_t snesUP = 0;
  uint8_t snesDOWN = 0;

  // swantroller pins.
  pinMode( SNESLATCH, OUTPUT );
  digitalWrite( SNESLATCH, 0 );
  pinMode( SNESCLK, OUTPUT );
  digitalWrite( SNESCLK, 1 );
  pinMode( SNESSERIAL, INPUT_PULLUP );

  // Set the latch to high for 12 us.
  digitalWrite( SNESLATCH, 1 );
  delayMicroseconds( 12 );
  digitalWrite( SNESLATCH, 0 );
  delayMicroseconds( 6 );

  // BLE
  if ( Serial.available() ) {
    Serial.readBytes(buf, 19);
    ble_data = bytesToUint16LE(buf);
    Serial.println(ble_data);
  }

  // Shift in the controller data.
  // Logic 0 means pressed.
  for ( uint8_t i = 0; i < 16; ++i ) {
    digitalWrite( SNESCLK, 0 );
    delayMicroseconds( 6 );
    // We only care about the first 15 bits.
    if ( i < 15 ) {
      uint8_t curDat = !digitalRead( SNESSERIAL );
      // BLE
      if ( ble_data != 0 ) {
        curDat = (ble_data >> i) & 1;
      }
      switch ( i ) {
        case 4:
          // Up
          snesUP = curDat;
          break;
        case 5:
          // Down
          snesDOWN = curDat;
          break;
        default:
          break;
      }
    }
    digitalWrite( SNESCLK, 1 );
    delayMicroseconds( 6 );
  }

  if ( snesUP && snesDOWN ) {
    Serial.println (F("swantroller mode ready!"));
  } else if( enableSwantrollerBLE ) {
    Serial.println (F("swantroller BLE mode ready!"));    
  } else {
    delay(300);  //added delay to give wireless ps2 module some time to startup, before configuring it
    psMode = true;
    Serial.println (F("ps mode ready!"));
  } 
}

void loop() {

  if ( Serial.available() && !enableSwantrollerBLE ) {
    Serial.println (F("enable swantroller BLE!"));
    enableSwantrollerBLE = true;
    psMode = false;
    modeCheck();
  } else if ( !Serial.available() && enableSwantrollerBLE ) {
    if ( !psMode ) {
      Serial.println (F("disable swantroller BLE!"));
      enableSwantrollerBLE = false;
    }
    modeCheck();
  }

  readController();

  updateWonderSignals();

  doComm();

  delay( POLLINT );

}

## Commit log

2026-03-28 Add BOM and CPL
    [swancolorhd-bom.csv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]
2026-04-09 Add swancolorHD Lite Data
    [bom.csv, swancolorHD_Lite_Connector_Cover.stl, swancolor_Lite_Case.stl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]
